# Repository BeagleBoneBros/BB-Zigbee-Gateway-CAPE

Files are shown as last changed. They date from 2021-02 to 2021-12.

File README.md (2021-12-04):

# Readme
- Purpose: The purpose of this project is to provide the Seeed Studio Beagle Bone Green Gateway with the ability to communicate via Zigbee through the means of a custom PCB that connects to the GPIO headers of the BeagleBone. In addition to providing the BeagleBone with the ability to communicate with a new protocol, it will also be able to host a MQTT Broker server that can be used to establish topics for smart devices such as lightbulbs, switches, and sensors. The Github for the MQTT Gateway Software can be found at the Github link below.

- Structure: This repository is designed and structured to be downloaded to a local machine such that the user can open the single "BeagleBone-Black-Cape.pro" file. All user-created footprints and symbols are included in this repository and are mapped relative to the .pro file.

- Created by: Tyler Beach, Zachary Wells, Adam Hood

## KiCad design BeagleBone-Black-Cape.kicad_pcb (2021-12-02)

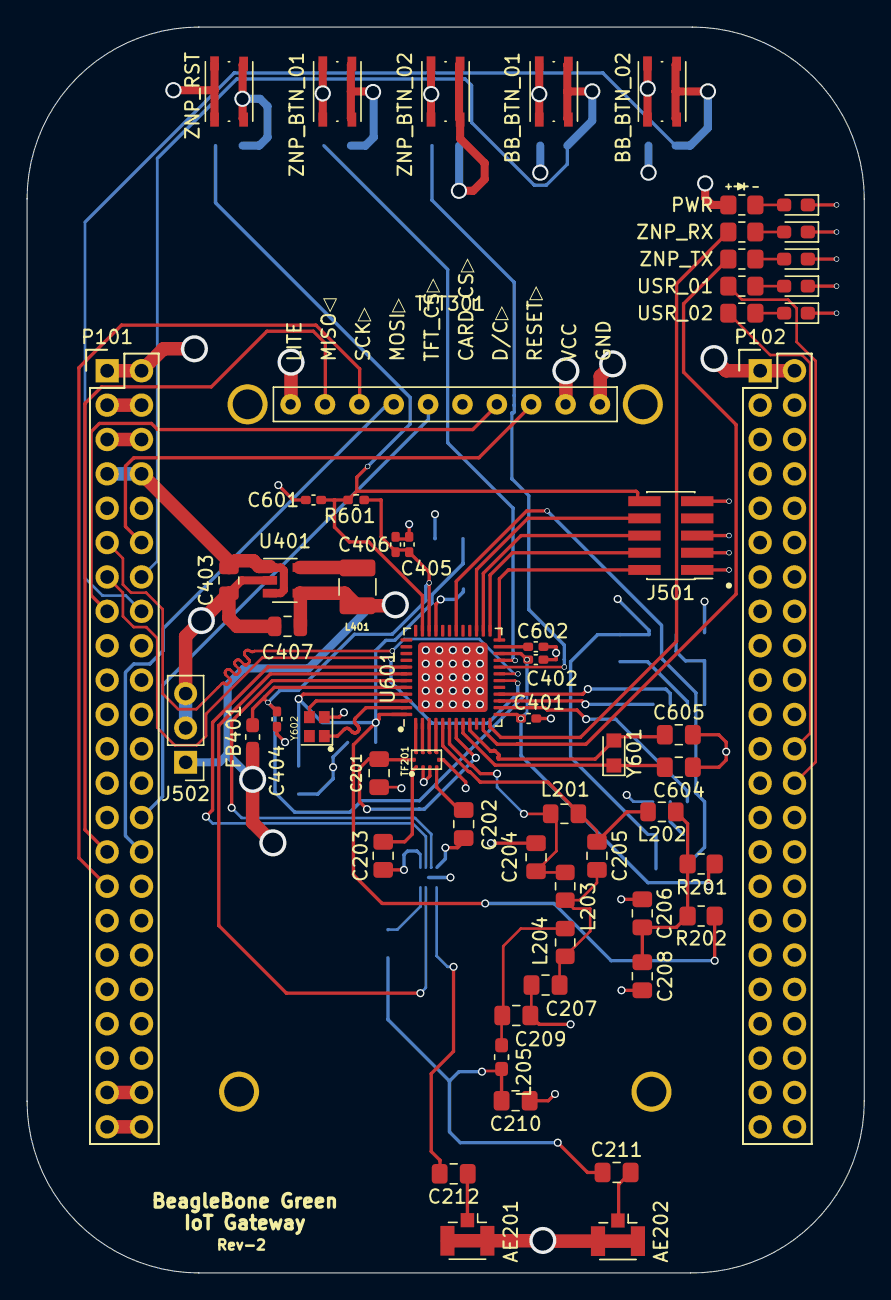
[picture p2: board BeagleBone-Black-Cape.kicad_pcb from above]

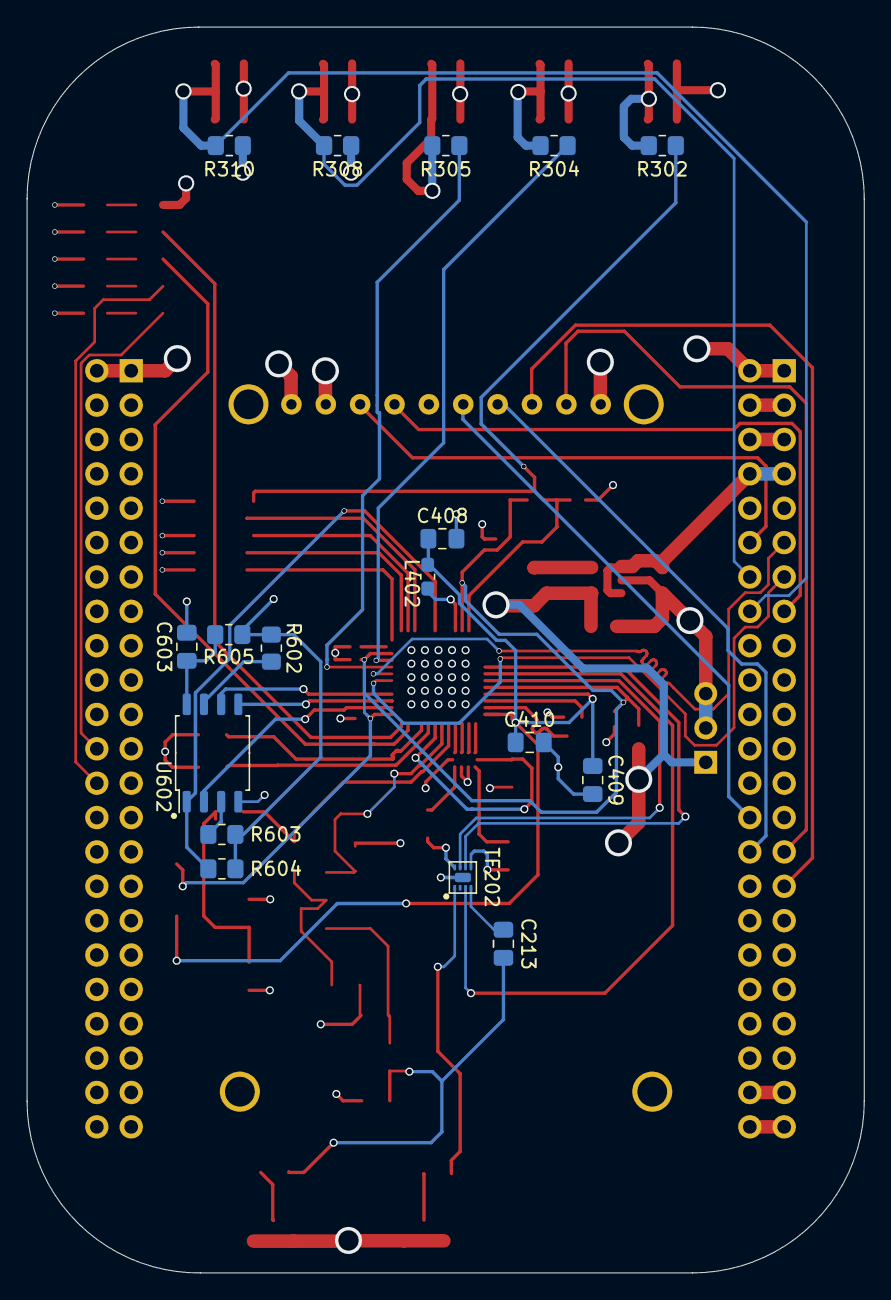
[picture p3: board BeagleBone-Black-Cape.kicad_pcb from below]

Board: 4 copper layers, 61.9 x 92.1 mm, 77 parts (17 on the bottom side), 72 nets.

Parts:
AE201, AE202: 50Ω; U.FL_Hirose_U.FL-R-SMT-1_Vertical
BB_BTN_01, BB_BTN_02: SW_Push; SW_Push_1P1T_NO_Vertical_Wuerth_434133025816
C201, C202: 100pF; C_0805_2012Metric_Pad1.18x1.45mm_HandSolder
C203, C213: 47pF; C_0805_2012Metric_Pad1.18x1.45mm_HandSolder
C204, C205: 1.2pF; C_0805_2012Metric_Pad1.18x1.45mm_HandSolder
C206: 12pF; C_0805_2012Metric_Pad1.18x1.45mm_HandSolder
C207: 2.7pF; C_0805_2012Metric_Pad1.18x1.45mm_HandSolder
C208: 10nF; C_0805_2012Metric_Pad1.18x1.45mm_HandSolder
C209: 1.8pF; C_0805_2012Metric_Pad1.18x1.45mm_HandSolder
C210: 1.5pF; C_0805_2012Metric_Pad1.18x1.45mm_HandSolder
C211, C212: DNF; C_0805_2012Metric_Pad1.18x1.45mm_HandSolder
C401, C402, C404, C406, C601: 0.1u; C_0402_1005Metric_Pad0.74x0.62mm_HandSolder
C403: 4.7uF; C_0805_2012Metric
C405: 22u; C_0402_1005Metric_Pad0.74x0.62mm_HandSolder
C407: 10uF; C_0805_2012Metric
C408: 22u; C_0805_2012Metric_Pad1.18x1.45mm_HandSolder
C409, C410, C603: 0.1u; C_0805_2012Metric_Pad1.18x1.45mm_HandSolder
C602: 1u; C_0402_1005Metric_Pad0.74x0.62mm_HandSolder
C604, C605: CAP; C_0805_2012Metric_Pad1.18x1.45mm_HandSolder
FB401: 1500 Ohm 500mA; L_0603_1608Metric_Pad1.05x0.95mm_HandSolder
J501: Conn_ARM_JTAG_SWD_10; PinHeader_2x05_P1.27mm_Vertical_SMD
J502: 3.3V; PinHeader_1x03_P2.54mm_Vertical
L201: 15nH; L_0805_2012Metric_Pad1.15x1.40mm_HandSolder
L202, L203: 3nH; L_0805_2012Metric_Pad1.15x1.40mm_HandSolder
L204: 1.8nH; L_0805_2012Metric_Pad1.15x1.40mm_HandSolder
L205: 1nH; L_0603_1608Metric_Pad1.05x0.95mm_HandSolder
L401: 2.2uH; L_1210_3225Metric
L402: 6.8u; L_0603_1608Metric_Pad1.05x0.95mm_HandSolder
P101, P102: BeagleBone_Black_Header; Socket_BeagleBone_Black
PWR: LED; LED_0603_1608Metric_Pad1.05x0.95mm_HandSolder
R201, R605: 0; R_0805_2012Metric_Pad1.20x1.40mm_HandSolder
R202: DNF; R_0805_2012Metric_Pad1.20x1.40mm_HandSolder
R301, R303, R306, R307, R309: R_US; R_0805_2012Metric_Pad1.20x1.40mm_HandSolder
R302, R304, R305: 100; R_0805_2012Metric_Pad1.20x1.40mm_HandSolder
R308, R310: 100k; R_0805_2012Metric_Pad1.20x1.40mm_HandSolder
R601: 100k; R_0402_1005Metric_Pad0.72x0.64mm_HandSolder
R602, R603: DNS; R_0805_2012Metric_Pad1.20x1.40mm_HandSolder
R604: 2.2k; R_0805_2012Metric_Pad1.20x1.40mm_HandSolder
TF201: IPC_1352P
TF202: SKY13317-373; SKY13317-373LF-BH
TFT301: ST7735_TFT; ST7735
U401: LM3671; SOT-23-5
U601: cc1352p; VQFN-48-1EP_7x7mm_P0.5mm_EP5.15x5.15mm
U602: MX25R8035FZUIL0; SOP-8_5.28x5.23mm_P1.27mm
USR_01, USR_02: LED; LED_0603_1608Metric_Pad1.05x0.95mm_HandSolder
Y601: 32.768kHz; Crystal_SMD_2012-2Pin_2.0x1.2mm_HandSoldering
Y602: 48MHz; Crystal_SMD_2016-4Pin_2.0x1.6mm
ZNP_BTN_01, ZNP_BTN_02: SW_Push; SW_Push_1P1T_NO_Vertical_Wuerth_434133025816
ZNP_RST: 612-LL3303F065QG; SW_Push_1P1T_NO_Vertical_Wuerth_434133025816
ZNP_RX: LED; LED_0603_1608Metric_Pad1.05x0.95mm_HandSolder
ZNP_TX: LED; LED_0603_1608Metric_Pad1.05x0.95mm_HandSolder

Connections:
2.4N: TF201.8, U601.2
2.4P: TF201.9, U601.1
+3V3: P101.3, P101.4
+5V: P101.5, P101.6
BB_BTN_1: BB_BTN_01.2, P101.14, R308.1
BB_BTN_2: BB_BTN_02.2, P101.16, R310.1
BB_LED_1: P102.24, R307.1
BB_LED_2: P102.26, R309.1
CS_TFT: P101.28, TFT301.5
D.C_TFT: P101.15, TFT301.7
DCDC_SW: L402.1, U601.33
GND: AE201.2, AE202.2, BB_BTN_01.1, BB_BTN_02.1, C201.1, C204.1, C206.2, C207.2, C208.2, C209.2, C210.2, C401.2, C402.2, C403.2, C404.2, C405.2, C406.2, C407.2, C408.2, C409.2, C410.2, C601.2, C602.2, C603.2, C604.2, C605.2, J501.3, J501.5, J501.9, J502.2, J502.3, P101.1, P101.2, P101.43, P101.44, P101.45, P101.46, P102.1, P102.2, PWR.1, TF201.2, TF201.3, TF201.10, TF202.9, TFT301.10, U401.2, U601.49, U602.4, USR_01.1, USR_02.1, Y602.2, ZNP_BTN_01.1, ZNP_BTN_02.1, ZNP_RST.1, ZNP_RX.1, ZNP_TX.1
MCU_BTN_1: R304.2, U601.21
MCU_BTN_2: R305.2, U601.20
MCU_LED_1: R303.1, U601.12
MCU_LED_2: R306.1, U601.11
MCU_RESET: C601.1, J501.10, R302.2, R601.1, U601.35
MCU_TCK: J501.4, U601.25
MCU_TDI: J501.8, U601.27
MCU_TDO: J501.6, U601.26
MCU_TMS: J501.2, U601.24
MCU_VDD: C407.1, FB401.2, J501.1, J502.1, L401.2, R301.1, R308.2, R310.2, R602.1, R603.1, R604.1, R605.1, TFT301.1, TFT301.9, U401.4
MISO_TFT: P101.29, TFT301.2
MOSI_TFT: P101.30, TFT301.4
unnamed: AE201.1, C212.1
unnamed: AE202.1, C211.2
unnamed: R307.2, USR_02.2
unnamed: R309.2, USR_01.2
unnamed: C202.1, TF202.5
unnamed: C202.2, TF201.4
unnamed: C203.1, TF202.8
unnamed: C203.2, TF201.1
unnamed: C205.2, C207.1, L203.2, L204.1
unnamed: C206.1, C208.1, L202.1, R201.2, R202.2
unnamed: C209.1, L204.2, L205.1
unnamed: C210.1, C211.1, C213.1, L205.2
unnamed: C212.2, TF202.1
unnamed: C602.1, U601.23
unnamed: C603.1, R605.2, U602.8
unnamed: L401.1, U401.5
unnamed: R303.2, ZNP_RX.2
unnamed: R306.2, ZNP_TX.2
unnamed: PWR.2, R301.2
unnamed: R302.1, ZNP_RST.2
unnamed: R304.1, ZNP_BTN_01.2
unnamed: R305.1, ZNP_BTN_02.2
unnamed: R602.2, U602.7
unnamed: R603.2, U602.3
unnamed: R604.2, U601.30, U602.1
unnamed: U601.14, U602.2
unnamed: U601.15, U602.5
unnamed: U601.16, U602.6
RST_TFT: P101.12, TFT301.8
RX_TX: C201.2, TF201.5, U601.7
SCK_TFT: P101.31, TFT301.3
SKY_RF1_20dBm: C213.2, TF202.4
SKY_V1_20DBM: TF202.3, U601.42
SKY_V2_SUB1G: TF202.6, U601.43
SKY_V3_2G4: TF202.7, U601.41
SUB1N: TF201.6, U601.4
SUB1P: TF201.7, U601.3
SYS_5V: C403.1, P101.7, P101.8, U401.1, U401.3
TX_20dB_N: C204.2, L201.2, L203.1, U601.6
TX_20dB_P: C205.1, L201.1, L202.2, U601.5
VDDR: C408.1, C409.1, C410.1, L402.2, R202.1, U601.45, U601.48
VDDS: C401.1, C402.1, C404.1, C405.1, C406.1, FB401.1, R201.1, R601.2, U601.13, U601.22, U601.34, U601.44
X32K_Q1: C604.1, U601.8, Y601.1
X32K_Q2: C605.1, U601.9, Y601.2
X48M_N: U601.46, Y602.3
X48M_P: U601.47, Y602.1
ZNP_RX: P101.13, U601.18
ZNP_TX: P101.11, U601.19

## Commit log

2021-02-23 fixed 1352 part, finished differential circuit
    [1352_antenna_subsystem.sch, BeagleBone-Black-Cape.sch]
2021-02-24 did more work on the schematic
    [1352_antenna_subsystem.sch, BeagleBone-Black-Cape.kicad_pcb]
2021-03-13 Finished schematic and PCB design for 2.4GHz and Sub 1GHz
    [1352_antenna_subsystem.sch, BeagleBone-Black-Cape.csv, BeagleBone-Black-Cape.kicad_pcb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]
2021-04-02 Added new symbols and footprints | Updated schematic for RF
    [1352_antenna_subsystem.sch, BeagleBone-Black-Cape.sch]
2021-04-03 Part way through rats nest of 20dB branch and RF switcher
    [1352_antenna_subsystem.sch, BeagleBone-Black-Cape.kicad_pcb]
2021-08-02 Just a summer update to make sure we're all on the same page
    [1352_antenna_subsystem.sch, BeagleBone-Black-Cape.kicad_pcb, BeagleBone-Black-Cape.sch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]
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2021-08-07 Drew up schematic for power subsystem
    [1352_antenna_subsystem.sch, BeagleBone-Black-Cape.sch, PowerSubSystem.sch]
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2021-08-24 Added PSU_ prepend to PSU specific global labels in the schematic
    [1352_antenna_subsystem.sch, BeagleBone-Black-Cape.sch, PowerSubSystem.sch]
2021-09-07 added crystal oscillator circuit
    [1352_antenna_subsystem.sch, BeagleBone-Black-Cape.sch, CrystolOscillator.sch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]
2021-09-09 straightened out traces going to MCU (lines 1-7)
    [BeagleBone-Black-Cape.kicad_pcb]
2021-09-09 Realigned some crooked traces on the PCB. Updated footprints for the PSU and associated components on behalf of Zach.
    [BeagleBone-Black-Cape.kicad_pcb, PowerSubSystem.sch]
2021-09-11 Replaced old PSU circuit with the new one
    [PowerSubSystem.sch]
2021-09-15 Added footprints and datasheets for oscillators
    [PowerSubSystem.sch]
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2021-09-17 PSU footprint validation done. Also updated reference values for L and C for that subsystem.
    [PowerSubSystem.sch]
2021-09-19 Added Buttons, LEDs and MCU to BB connections.
    [BeagleBone-Black-Cape.sch, UI_subsystem.sch]
2021-09-19 Fixed error with antenna system modification.
    [1352_antenna_subsystem.sch]
2021-09-20 Corrected RX/TX Connections to BB.
    [BeagleBone-Black-Cape-B_Cu.gbr, BeagleBone-Black-Cape-B_Mask.gbr, BeagleBone-Black-Cape-B_Paste.gbr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]
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2021-09-21 i'm about to say fuck it to the pcb. if it doesn't work out. return here
    [BeagleBone-Black-Cape.kicad_pcb, CrystolOscillator.sch, PowerSubSystem.sch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]
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2021-09-21 implementation of IPC and SDPT IC's are done. Still need to sort +20dBm branch
    [1352_antenna_subsystem.sch]
2021-09-22 part way through getting new ICs and other components back on the PCB
    [1352_antenna_subsystem.sch, BeagleBone-Black-Cape.kicad_pcb, BeagleBone-Black-Cape.sch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]
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2021-09-22 fixed the 20dBm branch and switched back to the 3 port band switcher IC
    [1352_antenna_subsystem.sch, BeagleBone-Black-Cape.kicad_pcb, CrystolOscillator.sch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]
2021-09-22 Added UI buttons, LEDs, Decoupling caps, MCU connections, and other good stuff.
    [1352_antenna_subsystem.sch, BeagleBone-Black-Cape.sch, CrystolOscillator.sch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]
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2021-09-22 Finished Adding MCU connections and combined crystal and MCU sheets.
    [1352_antenna_subsystem.sch, BeagleBone-Black-Cape.sch, CrystolOscillator.sch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]
2021-09-22 Fixed some Global labels.
    [UI_subsystem.sch]
2021-09-22 Added Footprints for UI, JTAG, and some power stuff.
    [1352_antenna_subsystem.sch, BeagleBone-Black-Cape.sch, Debug_subsystem.sch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]
2021-09-22 part way through PCB rework using new components. 62 unconnected.
    [1352_antenna_subsystem.sch, BeagleBone-Black-Cape.kicad_pcb, BeagleBone-Black-Cape.sch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]
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2021-09-24 finished RF side of schematic. We need ground planes and Xtals
    [1352_antenna_subsystem.sch, BeagleBone-Black-Cape.kicad_pcb]
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2021-09-25 Revert "Added Flash IC and PB/LED footprints."
    [BeagleBone-Black-Cape.sch, MCU_subsystem.sch, UI_subsystem.sch]
2021-09-27 FOUR LAYER BOARD CHANGE. We still need to adapt the other subsystems for four layers
    [1352_antenna_subsystem.sch, BeagleBone-Black-Cape.kicad_pcb, BeagleBone-Black-Cape.sch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]
2021-09-28 slowly but surely getting more things connected. trying to merge UI footprints. Standby
    [1352_antenna_subsystem.sch, BeagleBone-Black-Cape.kicad_pcb, BeagleBone-Black-Cape.sch]
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2021-09-28 relinked LED and BTN footprints. Need to make flash symbol again
    [BeagleBone-Black-Cape.kicad_pcb, MCU_subsystem.sch, UI_subsystem.sch]
2021-09-28 Recovered the .lib for flash symbol. Relinked in schematic
    [1352_antenna_subsystem.sch, BeagleBone-Black-Cape.sch, Debug_subsystem.sch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]
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2021-09-28 Connected PSUP, track lengths fixed for xtals
    PSUP has been connected to power and ground planes. Traces have been made larger for that. The trace lengths have been matched for the xtals so that they should have the same properties.
    [BeagleBone-Black-Cape.kicad_pcb]
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2021-09-29 Centered TFT display on the board
    Centered the TFT display on the board. The footprint was modified so the origin was the center of the component.
    [BeagleBone-Black-Cape.kicad_pcb]
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2021-09-29 slow and steady wins the race. Zach read the ZACH READ ME.txt
    [BeagleBone-Black-Cape.kicad_pcb, PowerSubSystem.sch]
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2021-10-11 Added more connections
    Connections added for the Push buttons, JTAG header, and LEDs
    [BeagleBone-Black-Cape.kicad_pcb]
2021-10-11 Massive PCB/Schematic Update
    The PCB has been completed, and the schematic has been updated to have the correct footprints
    [BeagleBone-Black-Cape.kicad_pcb, BeagleBone-Black-Cape.sch, MCU_subsystem.sch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]
2021-10-11 tyler once over. found two resistors that were missing traces. fixed.
    [BeagleBone-Black-Cape.kicad_pcb]
2021-10-11 Zach once over, resized some components, connected VDDS pins
    [BeagleBone-Black-Cape.kicad_pcb, PowerSubSystem.sch]
2021-10-11 Fixed Schematic connection issue and routed some missing traces.
    [1352_antenna_subsystem.sch, BeagleBone-Black-Cape.kicad_pcb]
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2021-11-06 filling around new through vias complete. need reviews. onto zach for LCD holes and index dots
    [BeagleBone-Black-Cape.kicad_pcb]
2021-11-07 updated footprint, updated some traces, added indexing dots
    [BeagleBone-Black-Cape.kicad_pcb]
2021-11-07 added silkscreen with board name and revision number
    [BeagleBone-Black-Cape.kicad_pcb]
2021-11-07 Fixed U601 p19 being connected to GND net instead of ZNP_TX
    [BeagleBone-Black-Cape.kicad_pcb]
2021-11-07 Connected U.FL ground pins to ground and 2x23 connector ground pins to each other
    [BeagleBone-Black-Cape.kicad_pcb]
2021-11-07 Used PCB cleanup tool w/o the "delete track segments connecting different nets" option (it keeps unlisted pins happy)
    [BeagleBone-Black-Cape.kicad_pcb]
2021-11-07 Updated schematic and a symbol so that Y602 pad 4 was connected to the gnd net
    [BeagleBone-Black-Cape.kicad_pcb, MCU_subsystem.sch]
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2021-11-07 undid the Y602 Pad thing after crossreferencing datasheet
    [BeagleBone-Black-Cape.kicad_pcb]
2021-11-07 Fixed silkscreens for buttons and LEDs
    [BeagleBone-Black-Cape.kicad_pcb]
2021-11-07 Apparently the schematic wasn't saved, and thus not commited. Here's that commit.
    [MCU_subsystem.sch]
2021-11-08 resolved DRC issues. Tyler check done. Awaiting 2/3 checks
    [BeagleBone-Black-Cape.kicad_pcb]
2021-11-09 Went over things with Smoak again. Small revisions
    [BeagleBone-Black-Cape.kicad_pcb]
2021-12-02 Last minute fixes before staging for public
    [1352_antenna_subsystem.sch, BeagleBone-Black-Cape.kicad_pcb]
2021-12-02 lib update so it only includes user-made library
    [1352_antenna_subsystem.sch, BeagleBone-Black-Cape.kicad_pcb, BeagleBone-Black-Cape.sch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]
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
